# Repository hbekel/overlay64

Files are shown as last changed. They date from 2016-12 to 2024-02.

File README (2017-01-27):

overlay64 - video overlay module

The overlay64 module allows superimposing predefined texts onto an
existing composite signal or onto the luminance portion of an s-video
signal depending on the states of up to sixteen digital input
lines. An LM1881 video sync separator IC is used to detect the
vertical and horizontal sync pulses of the video signal. An Atmega1284
uses these signals to synchronize with the video signal and to
superimpose text on the video display by bit-banging the corresponding
characters over SPI.

The user writes a simple configuration file that determines which
texts are to be displayed for which input line states. The
configuration file is converted to a binary format using the supplied
commandline tool before flashing it to the Atmegas's eeprom memory via
the USB interface.

Possible uses include displaying the state of control lines for
additional hardware installed in a homecomputer such as the Commodore
64, for example to display the currently selected kernal based on the
state of the control lines for a multi-kernal adapter.

An early working prototype can be seen in this video where it displays
the runtime configuration of the MixSID Stereo SID board:

https://www.youtube.com/watch?v=0exp2yM0WHM

This repository includes the complete sourcecode of the client
software, the firmware and all design files in KiCAD format.

LICENSING

Hardware licenced under CERN OHL v.1.2, see ./hardware/LICENSE.txt
Software and firmware licenced under GNU GPLv3, see ./LICENSE

The software contains MIT licensed code from
https://github.com/arkku/ihex for reading Intel HEX files, Copyright
(c) 2013-2015 Kimmo Kulovesi, see ./intelhex/LICENSE

The firmware contains the V-USB Driver (https://www.obdev.at/vusb),
(C)2008 Objective Development GmbH.

Distributed in the ./bootloader directory is the USBasp bootloader,
(C)2013 Stephan Baerwolf (matrixstorm@gmx.de) and (C)2008 Objective
Development GmbH (https://www.obdev.at/vusb).

In compliance with the terms of the (identical) V-USB driver and
USBasp bootloader licenses (./firmware/usbdrv/License.txt and
./bootloader/License.txt), the entire project is published under

http://www.henning-bekel.de/overlay64

In addition, this distribution contains

- a circuit diagram in PDF format, see ./hardware/overlay64-schematics.pdf
- the full source code for the host software in ./firmware
- this README file
- references to https://www.obdev.at/vusb

The USB Product and Vendor IDs for the Overlay64 USB device have kindly
been provided by OpenMoko, Inc (http://openmoko.org).

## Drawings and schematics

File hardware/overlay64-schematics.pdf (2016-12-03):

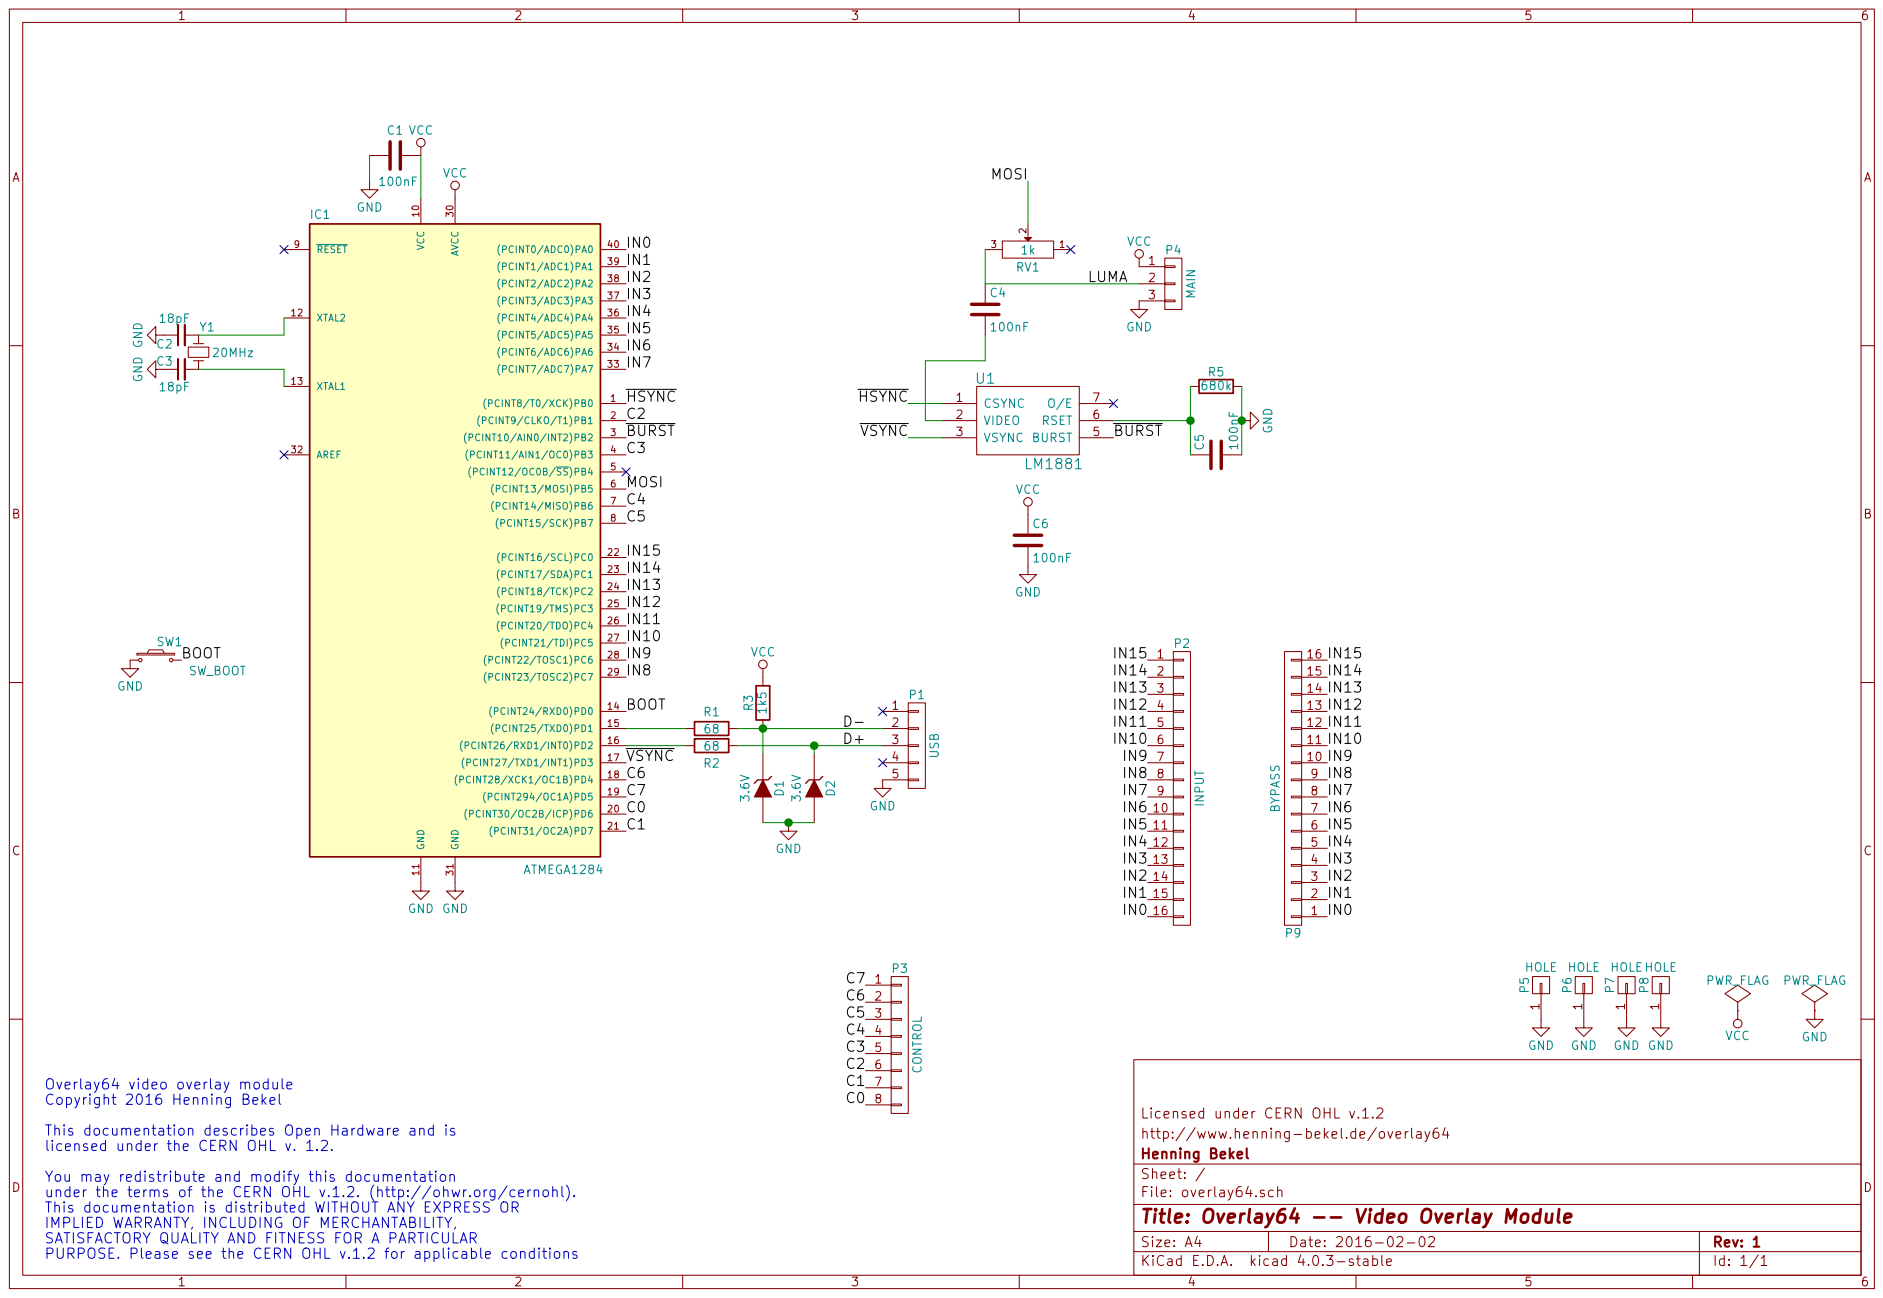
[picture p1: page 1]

1 P8 HOLE GND GND GND GND

Copyright 2016 Henning Bekel
This documentation describes Open Hardware and is
licensed under the CERN OHL v. 1.2.
You may redistribute and modify this documentation
under the terms of the CERN OHL v.1.2. (http://ohwr.org/cernohl).
This documentation is distributed WITHOUT ANY EXPRESS OR
IMPLIED WARRANTY, INCLUDING OF MERCHANTABILITY,
SATISFACTORY QUALITY AND FITNESS FOR A PARTICULAR
PURPOSE. Please see the CERN OHL v.1.2 for applicable conditions

Licensed under CERN OHL v.1.2
http://www.henning-bekel.de/overlay64
File: overlay64.sch Sheet: / Henning Bekel

Id: 1/1 Title: Overlay64 -- Video Overlay Module

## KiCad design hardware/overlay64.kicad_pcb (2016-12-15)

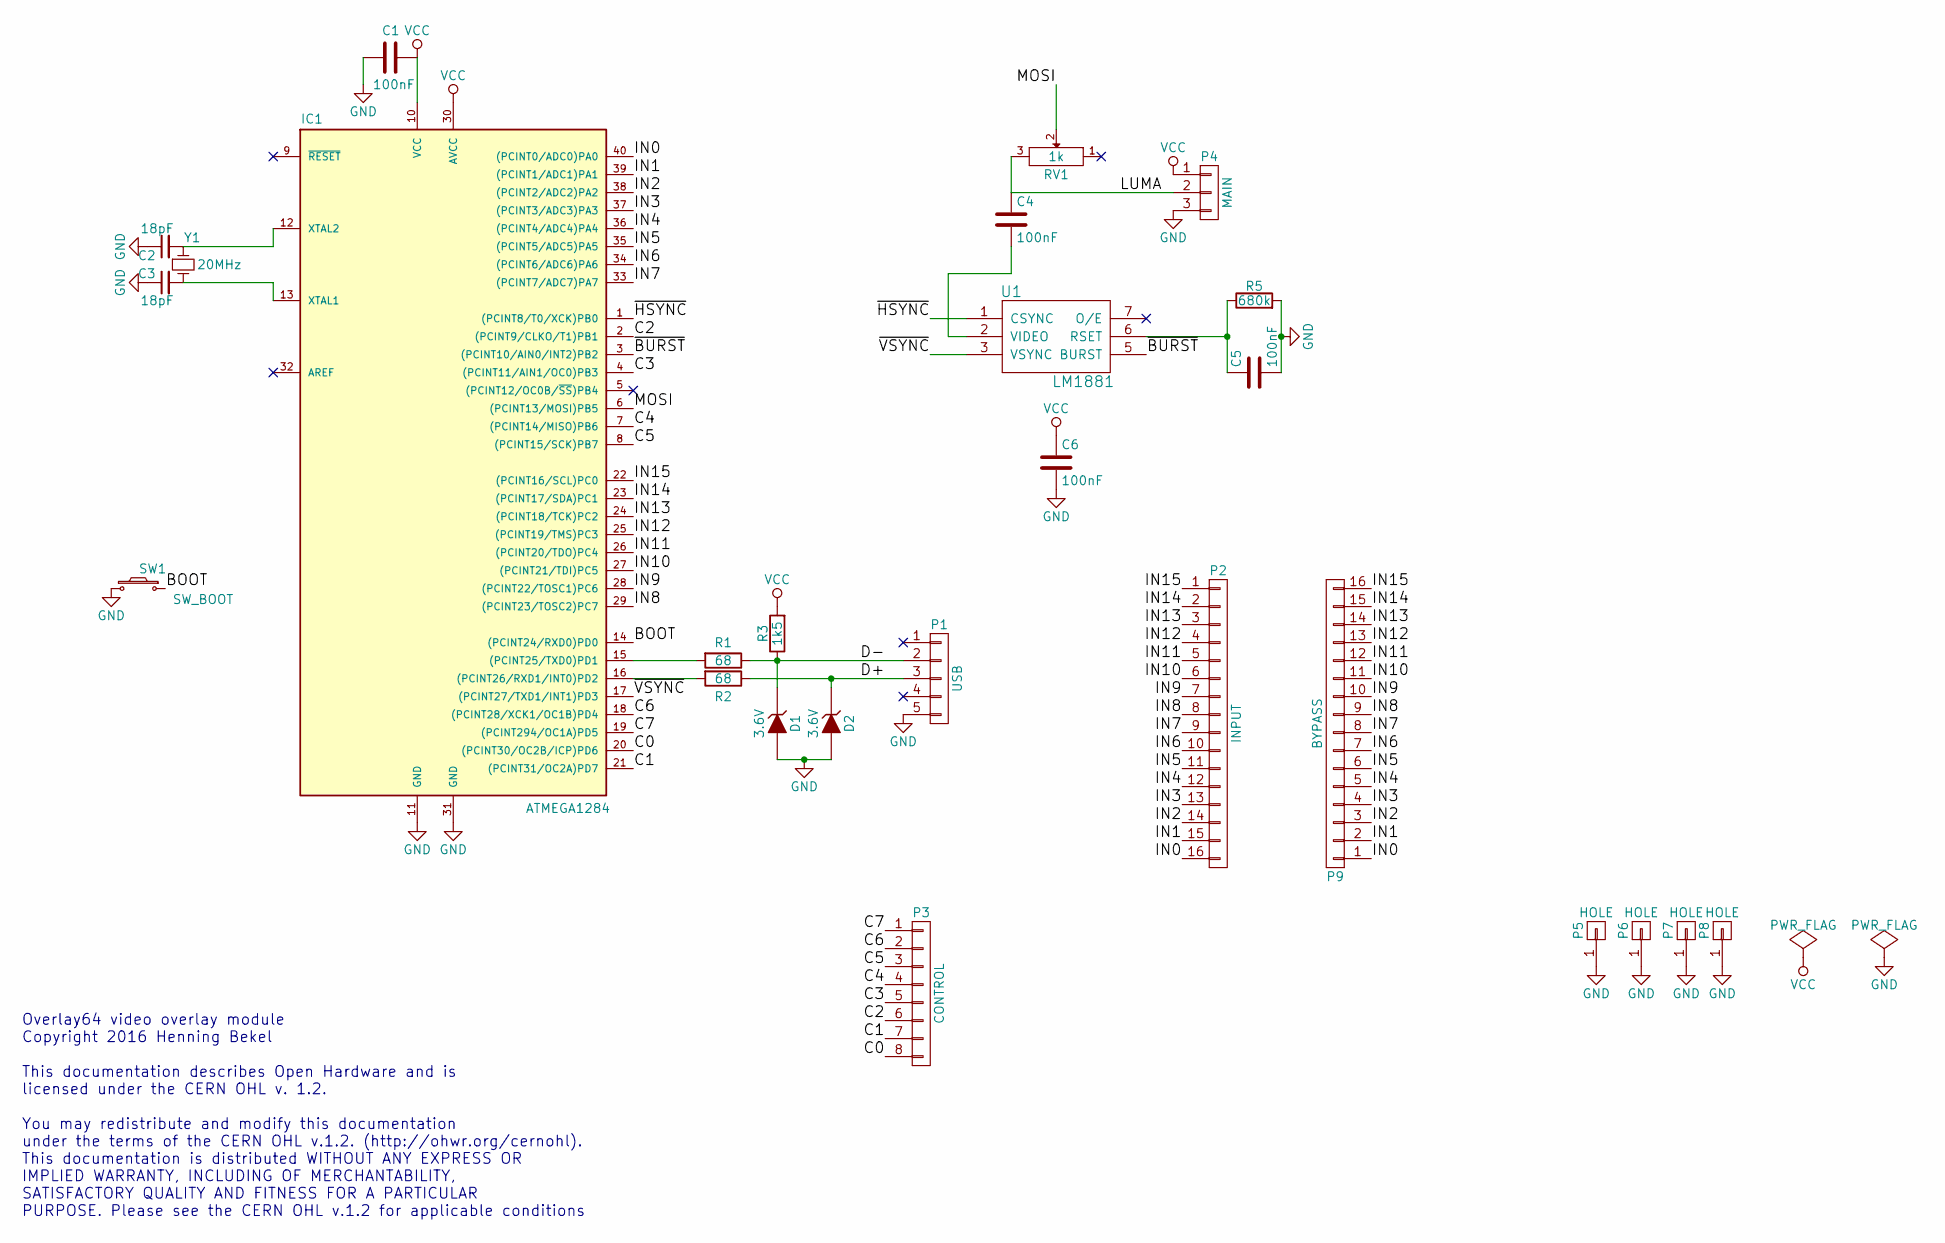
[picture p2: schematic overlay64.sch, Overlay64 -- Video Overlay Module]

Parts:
C1, C4, C5, C6: 100nF; C_Disc_D3_P2.5
C2, C3: 18pF; C_Disc_D3_P2.5
D1, D2: 3.6V; D3
IC1: ATMEGA1284; DIP-40_W15.24mm
P1: USB; USB-MINI-B-TH
P2: INPUT; Pin_Header_Angled_1x16
P3: CONTROL; Pin_Header_Angled_1x08
P4: MAIN; Pin_Header_Angled_1x03
P5, P6, P7, P8: HOLE; MountingHole_4mm
P9: BYPASS; Pin_Header_Angled_1x16
R1, R2: 68; R3
R3: 1k5; R3
R5: 680k; R3
RV1: 1k; Potentiometer_Bourns_3339P_Angular_ScrewUp
SW1: SW_BOOT; Button
U1: LM1881; DIP-8_W7.62mm
Y1: 20MHz; Crystal_HC49-U_Vertical

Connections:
/BOOT: IC1.14 ((PCINT24/RXD0)PD0), SW1.2
/C0: IC1.20 ((PCINT30/OC2B/ICP)PD6), P3.8
/C1: IC1.21 ((PCINT31/OC2A)PD7), P3.7
/C2: IC1.2 ((PCINT9/CLKO/T1)PB1), P3.6
/C3: IC1.4 ((PCINT11/AIN1/OC0)PB3), P3.5
/C4: IC1.7 ((PCINT14/MISO)PB6), P3.4
/C5: IC1.8 ((PCINT15/SCK)PB7), P3.3
/C6: IC1.18 ((PCINT28/XCK1/OC1B)PD4), P3.2
/C7: IC1.19 ((PCINT294/OC1A)PD5), P3.1
/D+: D2.1 (K), P1.3, R2.1
/D-: D1.1 (K), P1.2, R1.1, R3.1
/IN0: IC1.40 ((PCINT0/ADC0)PA0), P2.16, P9.1
/IN1: IC1.39 ((PCINT1/ADC1)PA1), P2.15, P9.2
/IN2: IC1.38 ((PCINT2/ADC2)PA2), P2.14, P9.3
/IN3: IC1.37 ((PCINT3/ADC3)PA3), P2.13, P9.4
/IN4: IC1.36 ((PCINT4/ADC4)PA4), P2.12, P9.5
/IN5: IC1.35 ((PCINT5/ADC5)PA5), P2.11, P9.6
/IN6: IC1.34 ((PCINT6/ADC6)PA6), P2.10, P9.7
/IN7: IC1.33 ((PCINT7/ADC7)PA7), P2.9, P9.8
/IN8: IC1.29 ((PCINT23/TOSC2)PC7), P2.8, P9.9
/IN9: IC1.28 ((PCINT22/TOSC1)PC6), P2.7, P9.10
/IN10: IC1.27 ((PCINT21/TDI)PC5), P2.6, P9.11
/IN11: IC1.26 ((PCINT20/TDO)PC4), P2.5, P9.12
/IN12: IC1.25 ((PCINT19/TMS)PC3), P2.4, P9.13
/IN13: IC1.24 ((PCINT18/TCK)PC2), P2.3, P9.14
/IN14: IC1.23 ((PCINT17/SDA)PC1), P2.2, P9.15
/IN15: IC1.22 ((PCINT16/SCL)PC0), P2.1, P9.16
/LUMA: C4.1, P4.2, RV1.3
/MOSI: IC1.6 ((PCINT13/MOSI)PB5), RV1.2
/~BURST: IC1.3 ((PCINT10/AIN0/INT2)PB2), U1.5 (BURST)
/~HSYNC: IC1.1 ((PCINT8/T0/XCK)PB0), U1.1 (CSYNC)
/~VSYNC: IC1.17 ((PCINT27/TXD1/INT1)PD3), U1.3 (VSYNC)
GND: C1.2, C2.1, C3.1, C5.2, C6.2, D1.2 (A), D2.2 (A), IC1.11 (GND), IC1.31 (GND), P1.5, P4.3, P5.1, P6.1, P7.1, P8.1, R5.2, SW1.1, U1.4 (GND)
unnamed: C2.2, IC1.12 (XTAL2), Y1.1
unnamed: C3.2, IC1.13 (XTAL1), Y1.2
unnamed: C4.2, U1.2 (VIDEO)
unnamed: C5.1, R5.1, U1.6 (RSET)
unnamed: IC1.15 ((PCINT25/TXD0)PD1), R1.2
unnamed: IC1.16 ((PCINT26/RXD1/INT0)PD2), R2.2
VCC: C1.1, C6.1, IC1.10 (VCC), IC1.30 (AVCC), P4.1, R3.2, U1.8 (VCC)

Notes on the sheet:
Overlay64 video overlay module Copyright 2016 Henning Bekel This documentation describes Open Hardware and is licensed under the CERN OHL v. 1.2. You may redistribute and modify this documentation under the terms of the CERN OHL v.1.2. (http://ohwr.org/cernohl). This documentation is distributed WI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

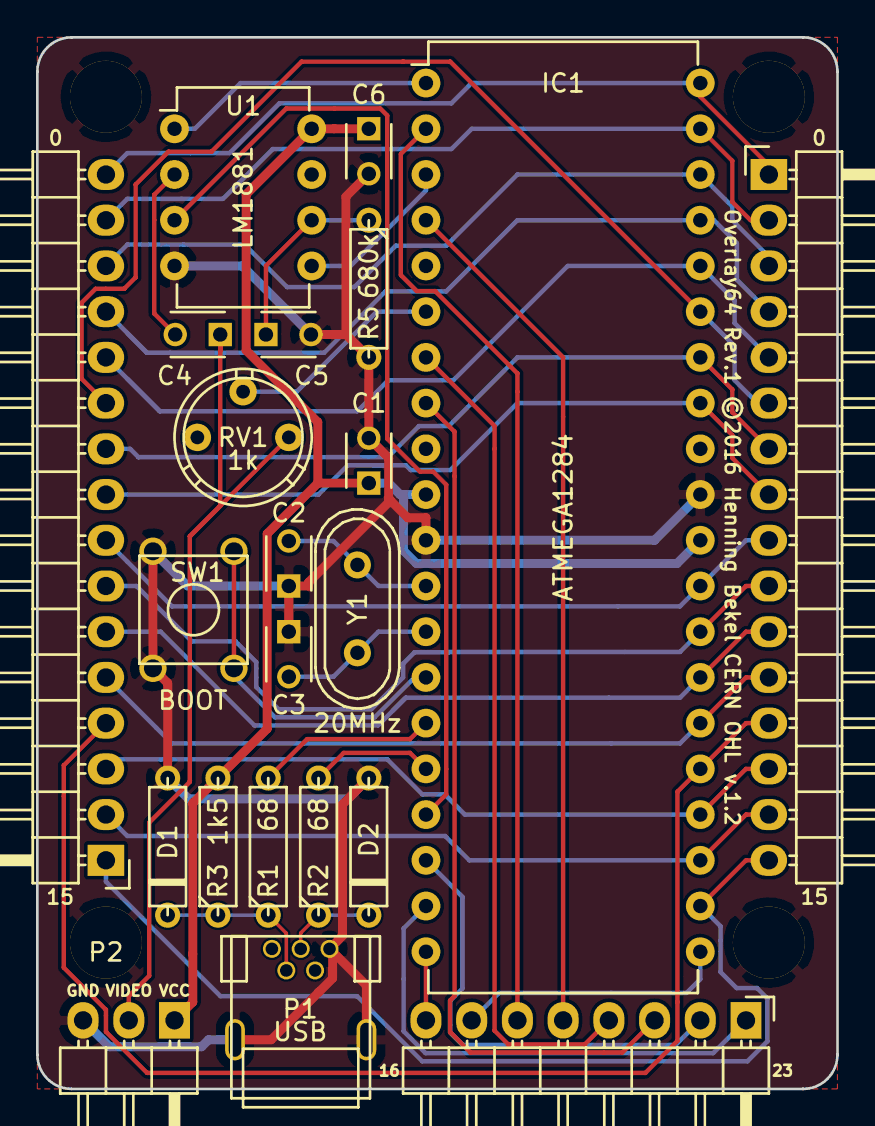
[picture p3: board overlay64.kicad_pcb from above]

Board: 2 copper layers, 44.5 x 58.4 mm, 26 parts (0 on the bottom side), 40 nets.

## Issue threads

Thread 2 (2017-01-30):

Device resets into Bootloader after config is sent

c0zmo, 2017-01-30:
I compiled software and firmware from todays sources (30 Jan 17). Now, with "overlay64 configure config.txt" the config is translated and sent to the device, but then it shows "Resetting device......" for 6-8 seconds. After that, the Overlay64 is in boot loader mode.
I'm using Prototype V2 Hardware, if that matters...

hbekel, 2017-01-30:
Please make sure you are actually using both the new firmware and the new software ($ which overlay64).

The device should not be in bootloader mode, since flashing the configuration does no longer involve the bootloader at all. The only reason I can think of is that you are still using the old client.

c0zmo, 2017-01-30:
Firmware and software are from the current branch. I just re-installed the firmware, and there the reset works:

```
markus@LE752:~/overlay64-master-20170130/firmware$ overlay64 update main.hex
Trying to parse Intel HEX format...OK
Parsed 17152 bytes starting at 0x00
Entering bootloader..
USBaspLoader (C)2008 by OBJECTIVE DEVELOPMENT Software GmbH
Updating application: 17152 of 17152 bytes transferred...OK
Resetting device...
overlay64 firmware 1.0 Jan 30 2017 18:50:01
```

But when flashing the config, the device stays in Bootloader-mode:

...
markus@LE752:~/overlay-config$ overlay64 configure o64-c0z.conf
Reading o64-c0z.conf...
SRAM:	 3249 of 16384 bytes used (13135 bytes free)
EEPROM:	  866 of  4096 bytes used ( 3230 bytes free)
Flashing configuration: 866 bytes...ok
Resetting device..........markus@LE752:~/overlay-config$ overlay64 identify
USBaspLoader (C)2008 by OBJECTIVE DEVELOPMENT Software GmbH
...

Using the reset-command works though.

c0zmo, 2017-09-14:
Just an update, even with the latest firmware this issue is still there. Maybe you can take a look at it this weekend. ;-)

hbekel, 2017-09-14:
I could not reproduce this issue and I haven't had anyone else reporting this, so I assume the issue is somewhere on your system. We can look into it tomorrow :)

c0zmo, 2017-09-20:
As it turned out, the problem seems to have been my self-compiled firmware. After we flashed the stock bootloader and firmware image with your computer on DoReCo, the problem disappeared.

Sorry for any inconvenience.
c0z

Closed 2017-11-05.

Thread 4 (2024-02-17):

New feature idea: draw bad lines, borders etc.

r1me, 2024-02-17:
How about drawing something else than text and would be helpful for coders and artists, like:
- bad lines (no doubt coders would like to have this feature) ignore FLD or whatever can delay bad lines, simply draw a dotted line where they normally occur
- borders of foreground (i.e. with same foreground and background color it's hard to tell if something is off center)
- margins of visible area (customizable x1, y1, x2, y2) once set that can be later used for calibrating projectors/CRTs for C64 video output, like https://csdb.dk/release/?id=201894 does

More or less that's what came to my mind.

hbekel, 2024-02-17:
Those ideas are nice, but unfortunately they are not really feasible for a simple project like this.

1. Drawing bad lines -- this is completely out of scope for this hardware. The overlay64 only sees a PAL signal, and knows nothing about the C64 or the VIC. Even if some other device, say an FPGA VIC implementation, would provide an additional output line and assert it for the duration of a bad line, the overlay would not be able to pick it up and mark it in realtime. It is either completely busy bitbanging on the luminance signal for displaying the current (previously calculated) text buffer, OR it is sampling input lines and preparing the text buffer for display, but it can't do both simultaneously.

2. Drawing horizontal or vertical lines could be achieved by using a custom font and preparing a static text screen. However, since the overlay produces a higher horizontal resolution than the VIC (about 53*8=424 pixels), you probably wont be able to line it up exactly with something like the edge of the VIC border.

hbekel, 2024-02-17:
By the way, if you had an fpga VIC or some other magical device providing such a hypothetical output line (that would go high during badlines), you wouldn't even need the overlay to mark that line, you'd just have to switch a transistor to pull the luminance signal high. Limit the current with a resistor to make it semi-transparent, and you could still see what happens on the actual VIC line.

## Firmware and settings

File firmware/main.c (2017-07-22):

//-----------------------------------------------------------------------------
// Overlay64 -- Video Overlay Driver -- Atmega1284 @ 20MHz
//-----------------------------------------------------------------------------

/*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
  You should have received a copy of the GNU General Public License
  along with this program.  If not, see <http://www.gnu.org/licenses/>.
*/

#include <avr/io.h>
#include <avr/wdt.h>
#include <avr/interrupt.h>
#include <avr/eeprom.h>
#include <util/delay.h>
#include <stdlib.h>
#include <string.h>
#include <ctype.h>

#include "main.h"
#include "font.h"
#include "eeprom.h"
#include "config.h"
#include "usbdrv/usbdrv.h"
#include "../protocol.h"

#define MOSI (1<<PB5)  // SPI output pin (where the actual bitmap data is send)
#define SS   (1<<PB4)  // SPI slave select (must be pulled up in master mode)

#define ENABLE_SPI  DDRB |= MOSI  // Enable the SPI output pin
#define DISABLE_SPI DDRB &= ~MOSI // Disable (tristate) the SPI output pin

volatile uint16_t scanline; // current scanline of the whole video frame

volatile Config* config;    // Configuration is read from eeprom

static volatile bool reset = false; // Requests a reset from USB
static volatile char version[64];   // Version string

static volatile uint8_t usbCommand;
static volatile uint16_t usbDataReceived;
static volatile uint16_t usbDataLength;
static volatile uint8_t *usbData;
static volatile uint16_t usbDataPos;

//-----------------------------------------------------------------------------

static void setup() {

  wdt_disable();
  CheckBootloader();
  
  // Initialize Version string and font data
  SetupVersionString();  
  SetupFont();
  
  // Create config and assign ports
  config = Config_new_with_ports(&PINA, &PINB, &PINC, &PIND);

  // Read config from eeprom
  Config_read(config, &eeprom) || Config_install_fallback(config);

  // Setup INT1, INT2 and PCINT8 pins
  DDRB &= ~(1<<PB2);
  PORTB |= (1<<PB2);

  DDRD &= ~(1<<PD3);
  PORTD |= (1<<PD3); 

  DDRB &= ~(1<<PB0);
  PORTB |= (1<<PB0);
  
  // Setup Interrupts
  EICRA = (1<<ISC11) | (1<<ISC21); // Sense INT1 and INT2 on falling edge
  EIMSK = (1<<INT1);               // Enable interrupt for INT1 (vsync)

  // Setupt Pin Change Interrupt PCINT8 (hsync)
  PCICR = (1<<PCIE1);
  PCMSK1 = (1<<PCINT8);

  // Turn off ADC  
  ADCSRA &= ~(1<<ADEN); 

  // Turn off JTAG
  MCUCR |= (1<<JTD);
  
  // Setup SPI 
  DDRB = SS | MOSI;                // /SS and MOSI as outputs
  SPCR =
    (1<<SPE) | (1<<MSTR) |         // Enable SPI as Master
    (1<<CPHA) | (1<<CPOL);         // Setup with falling edge of SCK
  SPSR = (1<<SPI2X);               // Double speed

  // Setup input and control lines
  Config_setup(config);
  
  // Setup USB
  usbInit();

  usbDeviceDisconnect();
  
  _delay_ms(500);

  usbDeviceConnect();
  
  // Enable Interrupts
  sei();   
}

//-----------------------------------------------------------------------------

void DisableDisplay(void) {
  EIMSK &= ~(1<<INT2);
  PCICR = 0; 
}

//-----------------------------------------------------------------------------

ISR(INT1_vect, ISR_NOBLOCK) { // VSYNC (each frame)...
  
  // Decrease timeout counters for all screens
  Config_tick(config);
   
  // Reset scanline counter
  scanline = 0;
}

//-----------------------------------------------------------------------------

ISR(PCINT1_vect, ISR_NOBLOCK) { // HSYNC (each line)...
  
  // Return immediately unless pin has changed to low
  if(PINB & (1<<PB0)) return;

  // When we enter here, there's a jitter of 1-3 cycles due to code
  // executed in the mainloop. Therefore we'll use the BACK PORCH
  // signal from the LM1881, which is triggered about 8us after HSYNC,
  // to trigger another interrupt while only executing NOPS. This way
  // the next interrupt gets triggered after a fixed number of cycles,
  // and the display is reasonable stable. There is still a slight
  // overall instability in the display since the video and avr clocks
  // are not perfectly synchronized to start with.

  // Disable PCINT1 (HSYNC), enable INT2 (BACK PORCH)
  PCICR = 0;
  EIMSK |= (1<<INT2);
  
  // Enter INT2_vect somewhere along these nops...
  ONEHUNDRED_AND_TEN_NOPS();

  // Now we're back from INT2_vect, at the end of the line

  // Disable the SPI pin to avoid disturbing the next hsync.
  DISABLE_SPI;
  
  // Disable INT2 (BACK PORCH), enable PCINT1 (HSYNC) again
  EIMSK &= ~(1<<INT2);
  PCICR = (1<<PCIE1);
}

//-----------------------------------------------------------------------------

ISR(INT2_vect, ISR_NOBLOCK) { // BACK PORCH (8us after HSYNC)

  uint8_t* row;   // Character data for the current row
  uint8_t line;   // Logical line of the visible screen
  uint8_t column; // Current character column in the current row 
  uint8_t byte;   // Current byte offset into the character bitmap
  
  scanline++;

  if(config->enabled && (scanline >= SCREEN_TOP && scanline < SCREEN_BOTTOM)) {

    // The display is enabled and we're on a vertical line inside of
    // the logical screen area, but still outside of the visible
    // horizonzal area. So there is time to precalculate some values
    // for the current line...
    
    line = scanline - SCREEN_TOP;
    row = config->rows[line / CHAR_HEIGHT];
    byte = line % CHAR_HEIGHT;

    // ...and to decide whether we're on an empty row...
    if(row == NULL) goto skip;

    // ...not an empty row, so we'll enable the SPI Output pin...
    ENABLE_SPI;
    
    // ...and wait until the visible area is reached
    FORTYTWO_NOPS();

    // Bitbang font data for each column via SPI
    for(column=0; column<SCREEN_COLUMNS; column++) {
      SPDR = font[row[column]*CHAR_HEIGHT+byte];
      TWO_NOPS();
    }
  }  
  else {
    // The display is not enabled or we're outside of the logical screen
    // or there is nothing to display on this row...
    
  skip:
    // We'll tristate the SPI pin again
    DISABLE_SPI;
  }
}

//-----------------------------------------------------------------------------

void Reset(void) {
  cli();
  wdt_enable(WDTO_250MS);
  for(;;);
}

//-----------------------------------------------------------------------------

void CheckBootloader(void) {
  DDRD &= ~(1<<PD0);
  PORTD |= (1<<PD0);

  if((PIND & (1<<PD0)) == 0) {
    EnterBootloader();
    Reset();
  }
}

//-----------------------------------------------------------------------------

void EnterBootloader(void) {
  eeprom_update_word((uint16_t *)0x0ffe, (uint16_t) 0xb0b0);
  reset = true;
}

//-----------------------------------------------------------------------------

void SetupVersionString(void) {

  char *v = "overlay64 firmware " xstr(VERSION) " " __DATE__ " " __TIME__;
  int len = strlen(v);

  for(uint8_t i=0; i<64; i++) {
    version[i] = '\0';
  }
  uint8_t o=0;
  
  for(uint8_t i=0; i<strlen(v); i++) {
    if(i>1 && v[i-1] == ' ' && v[i] == ' ') continue;
    version[o++] = v[i];
  }
}

//-----------------------------------------------------------------------------

USB_PUBLIC usbMsgLen_t usbFunctionSetup(uint8_t data[8]) {

  usbRequest_t *usbRequest = (void*) data;

  switch(usbRequest->bRequest) {

  case OVERLAY64_FLASH:
    DisableDisplay();
    
    usbCommand = usbRequest->bRequest;
    usbDataLength = usbRequest->wLength.word;
    usbDataReceived = 0;
    
    if(usbData == NULL) {
      usbData = (uint8_t*) calloc(1, sizeof(uint8_t) * usbDataLength);
    }
    
    return USB_NO_MSG;
    break;
    
  case OVERLAY64_BOOT:
    DisableDisplay();
    EnterBootloader();   
    break;

  case OVERLAY64_RESET:
    eeprom_update_word((uint16_t *)0x0ffe, (uint16_t) 0xffff);
    reset = true;
    break;
    
  case OVERLAY64_IDENTIFY:
    usbMsgPtr = (uchar *) version;
    return strlen((const char*)version)+1;
    break;
    
  default:
    break;
  }
  return 0;
}

//-----------------------------------------------------------------------------

USB_PUBLIC uchar usbFunctionWrite(uchar *data, uchar len) {

  for(int i=0; usbDataReceived < usbDataLength && i < len; i++, usbDataReceived++) {
    usbData[usbDataReceived] = (uint8_t) data[i];
  }

  if(usbDataReceived < usbDataLength) {
    return 0;
  }
  else {
    if(usbCommand == OVERLAY64_FLASH) {
      FlashConfigurationFromUSBData();
    }
  }
  
  free((void*)usbData);
  usbData = NULL;
  return 1;
}

//-----------------------------------------------------------------------------

void FlashConfigurationFromUSBData(void) {  
  fwrite((void*)usbData, sizeof(uint8_t), usbDataLength, &eeprom);
  eeprom_update_word((uint16_t *)0x0ffe, (uint16_t) 0xffff);
  reset = true;
}

//-----------------------------------------------------------------------------

void SetupFont(void) {
  for(uint16_t i=0; i<96*8; i++) {
    font[i] = pgm_read_byte(&(_font[i]));
  }
}

//-----------------------------------------------------------------------------

int main(void) {

  setup();

  while(1) {

    // Poll for USB messages
    usbPoll();

    // If reset is requested, allow USB communication to finish, then reset
    if(reset) {
      _delay_ms(250);
      Reset();
    }
    
    // Sample input/control lines and update screen according to user config
    Config_apply(config);
  }
  
  return 0;    
}

//-----------------------------------------------------------------------------

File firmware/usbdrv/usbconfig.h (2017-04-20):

/* Name: usbconfig.h
 * Project: V-USB, virtual USB port for Atmel's(r) AVR(r) microcontrollers
 * Author: Christian Starkjohann
 * Creation Date: 2005-04-01
 * Tabsize: 4
 * Copyright: (c) 2005 by OBJECTIVE DEVELOPMENT Software GmbH
 * License: GNU GPL v2 (see License.txt), GNU GPL v3 or proprietary (CommercialLicense.txt)
 */

#ifndef __usbconfig_h_included__
#define __usbconfig_h_included__

/*
General Description:
This file is an example configuration (with inline documentation) for the USB
driver. It configures V-USB for USB D+ connected to Port D bit 2 (which is
also hardware interrupt 0 on many devices) and USB D- to Port D bit 4. You may
wire the lines to any other port, as long as D+ is also wired to INT0 (or any
other hardware interrupt, as long as it is the highest level interrupt, see
section at the end of this file).
+ To create your own usbconfig.h file, copy this file to your project's
+ firmware source directory) and rename it to "usbconfig.h".
+ Then edit it accordingly.
*/

/* ---------------------------- Hardware Config ---------------------------- */

#define USB_CFG_IOPORTNAME      D
/* This is the port where the USB bus is connected. When you configure it to
 * "B", the registers PORTB, PINB and DDRB will be used.
 */
#define USB_CFG_DMINUS_BIT      1
/* This is the bit number in USB_CFG_IOPORT where the USB D- line is connected.
 * This may be any bit in the port.
 */
#define USB_CFG_DPLUS_BIT       2
/* This is the bit number in USB_CFG_IOPORT where the USB D+ line is connected.
 * This may be any bit in the port. Please note that D+ must also be connected
 * to interrupt pin INT0! [You can also use other interrupts, see section
 * "Optional MCU Description" below, or you can connect D- to the interrupt, as
 * it is required if you use the USB_COUNT_SOF feature. If you use D- for the
 * interrupt, the USB interrupt will also be triggered at Start-Of-Frame
 * markers every millisecond.]
 */
#define USB_CFG_CLOCK_KHZ       (F_CPU/1000)
/* Clock rate of the AVR in kHz. Legal values are 12000, 12800, 15000, 16000,
 * 16500, 18000 and 20000. The 12.8 MHz and 16.5 MHz versions of the code
 * require no crystal, they tolerate +/- 1% deviation from the nominal
 * frequency. All other rates require a precision of 2000 ppm and thus a
 * crystal!
 * Since F_CPU should be defined to your actual clock rate anyway, you should
 * not need to modify this setting.
 */
#define USB_CFG_CHECK_CRC       0
/* Define this to 1 if you want that the driver checks integrity of incoming
 * data packets (CRC checks). CRC checks cost quite a bit of code size and are
 * currently only available for 18 MHz crystal clock. You must choose
 * USB_CFG_CLOCK_KHZ = 18000 if you enable this option.
 */

/* ----------------------- Optional Hardware Config ------------------------ */

/* #define USB_CFG_PULLUP_IOPORTNAME   D */
/* If you connect the 1.5k pullup resistor from D- to a port pin instead of
 * V+, you can connect and disconnect the device from firmware by calling
 * the macros usbDeviceConnect() and usbDeviceDisconnect() (see usbdrv.h).
 * This constant defines the port on which the pullup resistor is connected.
 */
/* #define USB_CFG_PULLUP_BIT          4 */
/* This constant defines the bit number in USB_CFG_PULLUP_IOPORT (defined
 * above) where the 1.5k pullup resistor is connected. See description
 * above for details.
 */

/* --------------------------- Functional Range ---------------------------- */
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

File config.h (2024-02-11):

/*
overlay64 -- video overlay module
Copyright (C) 2016 Henning Bekel

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
You should have received a copy of the GNU General Public License
along with this program.  If not, see <http://www.gnu.org/licenses/>.
*/

#ifndef CONFIG_H
#define CONFIG_H

#include <stdint.h>
#include <stdbool.h>
#include <stdio.h>

#define CHAR_WIDTH    8
#define CHAR_HEIGHT   8

#define SCREEN_COLUMNS 52
#define SCREEN_ROWS    30

#define SCREEN_TOP    46
#define SCREEN_BOTTOM SCREEN_TOP + CHAR_HEIGHT * SCREEN_ROWS

#define MODE_MANUAL 1
#define MODE_NOTIFY 2
#define MODE_ALWAYS 3

#define NUM_PINS 24

#define ACTION_NONE  0x00
#define ACTION_WRITE 0x01
#define ACTION_CLEAR 0x02

extern uint8_t CONFIG_MAGIC[2];

typedef struct {
  uint8_t volatile *port; // pointer into Config->ports
  uint8_t pos;
  uint8_t edge[2];
} Pin;

typedef struct {
  Pin* pin;

  uint8_t mode;
  bool asserted;

  uint8_t *screens; // index into config->screens
  uint8_t num_screens;

} Control;

typedef struct {
  void *screen;
  uint8_t action;
  uint8_t row;
  uint8_t col;
  uint16_t len;
  char* string; // pointer into config->strings
} Command;

typedef struct {
  void *screen;
  Command **commands;
  uint8_t num_commands;
} CommandList;

typedef struct {
  void *screen;
  Pin **pins; // pointers into Config->pins
  uint8_t num_pins;
  uint8_t value;

  CommandList *command_list; // immediate commands

  CommandList **command_lists; // one command list for each state
  uint8_t num_command_lists;
} Sample;

typedef struct {
  uint8_t mode;
  bool enabled;
  uint8_t timeout;

  Sample **samples;
  uint8_t num_samples;

  Control **controls;
  uint8_t num_controls;

  CommandList* commands;

  uint8_t **rows;

} Screen;

typedef struct {
  uint8_t volatile *ports[4]; // the actual ports to use
  Pin *pins[NUM_PINS];        // the available pins

  bool enabled;
  uint8_t timeout;

  char **strings;
  uint8_t num_strings;

  Control **controls;
  uint8_t num_controls;

  Screen **screens;
  uint8_t num_screens;

  uint8_t **rows;

} Config;

volatile Config *Config_new(void);
volatile Config* Config_new_with_ports(uint8_t volatile *a,
                                       uint8_t volatile *b,
                                       uint8_t volatile *c,
                                       uint8_t volatile *d);

Control* Config_add_control(volatile Config *self, Control* control);
Screen* Config_add_screen(volatile Config *self, Screen* screen);
bool Config_has_string(volatile Config *self, char* string, uint8_t *index);
char *Config_add_string(volatile Config *self, char* string);
bool Config_read(volatile Config *self, FILE *in);
void Config_each_command(volatile Config* self,
                         void (*callback)(Screen* screen, Command* command));
void Config_allocate_row_for_command(Screen* screen, Command *command);
void Config_allocate_rows(volatile Config *self);
void Config_assign_controls_to_screens(volatile Config* self);
bool Config_install_fallback(volatile Config* self);
void Config_free(volatile Config* self);

Control* Control_new(void);
void Control_add_screen(Control* self, uint8_t index);
void Control_read(Control* self, FILE* in);
void Control_free(Control* self);

Screen* Screen_new(void);
Screen* Screen_add_control(Screen *self, Control* control);
Sample* Screen_add_sample(Screen *self, Sample* sample);
void Screen_read(Screen* self, FILE* in);
void Screen_free(Screen* self);

Sample* Sample_new(Screen* screen);
Pin* Sample_add_pin(Sample* self, Pin* pin);
void Sample_read(Sample* self, FILE* in);
CommandList* Sample_add_commands(Sample* self, CommandList* commands);
void Sample_free(Sample* self);

Command* Command_new(Screen *screen);
void Command_set_string(Command* self, char *string);
bool Command_equals(Command* self, Command* command);
void Command_read(Command* self, FILE* in);
void Command_free(Command* self);

CommandList* CommandList_new(Screen* screen);
Command* CommandList_add_command(CommandList *self, Command* command);
void CommandList_read(CommandList *self, FILE *in);
void CommandList_free(CommandList* self);

Pin *Pin_new(volatile Config* config, uint8_t port, uint8_t pos);
void Pin_free(Pin *self);

#endif // CONFIG_H

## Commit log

2016-01-22 Intial commit, rough draft
    [overlay64.kicad_pcb, overlay64.sch]
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2016-01-26 Hardware: Schematics switched to 1284P including USB, still drafting...
    [overlay64.sch]
2016-01-27 Hardware: Switched to atmega32p, updated to current state on breadboard
    [overlay64.sch]
2016-01-27 Hardware: Added vic sockets, layed out components (rough draft)
    [overlay64.kicad_pcb, overlay64.sch]
2016-01-28 Hardware: Removed VIC-Sockets and pcb layout
    Designing this as a VIC-Adpater-board is too complicated, and maybe
    not possible (depending on what the modulator still does to the signal
    to make it a proper C/Y signal).
    It's probably simpler to get LUMA from the connector internally.
    [overlay64.kicad_pcb, overlay64.sch]
2016-01-28 Hardware: Updated schematics, Added /OE, resistor before transistor base
    [overlay64.sch]
2016-01-29 Firmware: Fixed conditional compile in Makefile
    [main.c]
2016-02-02 Firmware: Fixed sparse memory model, expanded screen to 53x30 chars max
    Always allocate a complete row of screen memory for each row used. This
    further speeds up access to the character data, resulting in even smaller
    horizontal gaps between characters.
    [config.c, config.h, main.c]
2016-02-02 Software: Fixed invalid free in Command_parse, fixed footprint calculation
2016-02-02 Hardware: Removed wrong "no connection" symbol on IN7
    [overlay64.sch]
2016-02-02 Hardware: Added dual 14 pin header for bypassing the inputs
    [overlay64.sch]
2016-02-02 Hardware: Specified correct transistor type (BC547B)
    [overlay64.sch]
2016-02-03 Hardware: Added jumper for backdrop (decreased luminance as background)
    [overlay64.sch]
2016-02-06 Firmware: Removed useless malloc for empty rows, use NULL pointers instead
    Since empty rows are skipped from display now, the memory allocated for the
    empty row is no longer used, so it can be saved.
    [config.c, config.h, main.c]
2016-02-06 Hardware: First draft of pcb layout (rough)
    [overlay64.dsn, overlay64.kicad_pcb, overlay64.sch]
2016-02-06 Revert "Firmware: Simplified rendering code"
    This reverts commit e1bf8339e2f7e9adda6c1a24c2130ea8e0cfa4bb.
    [main.c]
2016-02-08 Firmware: Added global output enable pin, improved control logic
    The former OE (output enable) pin has been renamed to OR (output request)
    and another pin has been introduced as OE (output enable).
    The output enable pin now directly controls whether or not the display is
    active. When low, the display is enabled. When going high again, the
    display is immediately disabled, regardless of any running timeouts from a
    former output request.
    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
    [overlay64.sch]
2016-02-08 Hardware: Updated netlist to include OE/OR pins
    [overlay64.kicad_pcb]
2016-02-08 Hardware: Adjusted input pin connections to new logical layout
    [overlay64.dsn, overlay64.kicad_pcb, overlay64.sch]
2016-05-09 Hardware: Rearranged components, rerouting...
    [overlay64.dsn, overlay64.kicad_pcb, overlay64.sch]
2016-05-24 Hardware: Improved routing
    [overlay64.kicad_pcb]
2016-05-24 Hardware: Fixed orientation/wiring for brightness pot
    [overlay64.kicad_pcb, overlay64.sch]
2016-05-24 Production: Added gerber files for Revision 1
    [overlay64.gbl, overlay64.gbs, overlay64.gtl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]
2016-07-21 Firmware/Software: Fixed memory footprint calculation, minor changes
    [config.c]
2016-07-28 Hardware: Changed schematics for 1284p, removed pcb layout
    [overlay64.kicad_pcb, overlay64.sch]
2016-07-28 Hardware: Corrected OE/OR pins, Software: Disable inputs for now
    [overlay64.sch]
2016-08-02 Firmware: Now applying config in main thread, stabilized hsync interrupts
    [config.c, config.h, main.c]
2016-08-02 Hardware: Updated schematics, added BURST signal connection
    [overlay64.sch]
2016-08-12 Hardware: Added custom components, started layout
    [overlay64.kicad_pcb, overlay64.sch]
2016-08-12 Hardware: First draft of new pcb layout, autorouted
    [overlay64.dsn, overlay64.kicad_pcb]
2016-08-14 Project: Fixed some file attributes, set alpha project version
    [overlay64.dsn, overlay64.sch]
2016-08-18 Hardware: Added jumpers for manually entering the bootloader
    [overlay64.dsn, overlay64.kicad_pcb, overlay64.sch]
2016-08-19 Hardware: Prototype 2, rearranged, rerouted, added gerber files
    [overlay64.dsn, overlay64.kicad_pcb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]
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2016-09-01 Firmware: Fixed jitter from USB INT0, ensure enumeration
    [main.c]
2016-09-06 Hardware: Removed explicit OE/OR lines, relabeled control lines
    [overlay64.kicad_pcb, overlay64.sch]
2016-09-07 Firmware: Fixed some bugs, sample pins only once per pass
    [config.c]
2016-09-08 Firmware: Fixed problems with controls/samples/notifications
    When a manual control enables a screen, cancel any pending
    notification for that screen.
    Initially sample the input/control lines, otherwise the first
    sampling is already interpreted as a change, triggering automatic
    screens.
    [config.c]
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2016-09-22 Hardware: Improved USB signal routing
    [overlay64.kicad_pcb]
2016-10-02 Software/Firmware: Removed distinction between input and control lines
    Now all input pins can be used either as an input line for sampling
    or as a control line. Pins are thus indexed from 0 to 23. The first
    16 lines are the ones passed through on the left and right side, the
    last 8 lines are the ones right of the USB adapter, where pin 16 is
    left and pin 23 is right.
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2016-11-27 Hardware: Removed backdrop option, single boot button, rerouting...
    [overlay64.dsn, overlay64.kicad_pcb, overlay64.sch]
2016-12-01 Hardware: Added 3d models for button and diodes
    [overlay64.kicad_pcb]
2016-12-01 Software: Implemented convert, configure, update and boot commands
    Also added options --version, --help, --device
2016-12-01 Firmware: Added fallback configuration in case of empty eeprom
    The fallback configuration simply displays some information
    when no valid configuation is found in eeprom memory. This will
    most likely be the case when the device is powered on for the
    first time.
2016-12-02 Software: Added reset command, improved boot command
    [main.c]
2016-12-03 Project: Hardware documentation licensed under CERN OHL 1.2
    [overlay64.kicad_pcb, overlay64.sch]
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2016-12-06 Software: Improved error messages for missing USB devices
2016-12-06 Hardware: Added rendering of component placement
    [overlay64.kicad_pcb]
2016-12-06 Software: Improved error messages, detect and report doubleclick on windows
    Complain if the user doubleclicks the .exe on windows and suggest running
    from a command prompt instead.
    Improved error messages for missing USB devices, added role to device info
    Fixed compiler warning concerning _fileno for native cygwin builds
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2016-12-08 Hardware: Updated gerber files for revision 1
    [overlay64.kicad_pcb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]
2016-12-09 Firmware: Added support for lowercase characters
    Expanded font to include all printable 7-bit ASCII characters
    (ASCII codes 32-127).
    Also some preparations for making the font customizable by the user.
    The default font.rom file in ./firmware now includes characters in
    ASCII order, which means it is no longer directly compatible with a
    c64 font file.
    Also, the font has been moved to a fixed address in PROGMEM (0x5000),
    which will allow selectively updating it from an appropriate .hex file
    using the update command in the future.
2016-12-10 Software/Firmware: More changes towards user customizable fonts
    The font data is now properly stored at a fixed progmem address
    and copied to sram at startup.
    Fixed size calculations when reading segmented ihex files, added
    code to allow writing in hex format files as well.
    Only ihex format is now allowed as input for the update command.
    [main.c]
2016-12-11 Software: Added command to convert c64 charsets to overlayt64 fonts
    $ overlay64 font-convert <infile> <outfile>
    $ overlay64 font-update <infile>
    The "font-convert" command converts a C64 charset image to an
    overlay64 font file.
    The "font" command has been renamed to "font-update" (transfer
    an overlay64 font file to the device).
2016-12-15 Hardware: Improved silkscreen, added labels
    [overlay64.kicad_pcb]
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2017-01-06 Firmware: Prevent writing past the end of a row
    [config.c]
2017-01-06 Software: Fixed bugs in parsing/reading clear commands
    [config.c]
2017-01-10 Version 1.0
    [overlay64.drl, overlay64.gbl, overlay64.gbs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]
2017-01-27 Software/Firmware: Improved display logic, improved flashing, bugfixes
    Improved screen logic. Independent of the screen or control mode,
    a screen is only enabled if at least one write command is found
    to be effective. This can either be an unconditional write command
    or a write command depending on a certain input line state.
    In addition, a sample does not need to cover all possible input
    line states anymore.
    The new screen mode "always" has been added to allow a screen to
    be always enabled regardless of control lines being asserted or
    input lines being changed, as far as at least one write command
    is effective.
    Combining both features allows for text to be displayed
    permanently when one o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
    [config.c, config.h, main.c]
2017-01-31 Firmware: Assure bootloader flag is cleared before reset
    [main.c]
2017-04-11 Firmware: Improved chances of proper device enumeration for some Windows versions.
    It appears that on some Windows versions and/or installations device
    enumeration may fail due to Windows giving up on enumeration too early.
    A workaround for the current 1.1 version of the firmware is to disconnect
    the cable from the PC when the device is powered on and to connect
    it to the PC after a few seconds.
    Thus the previously introduced delay has been removed again. Note
    that enumeration on Linux is/was not negatively affected by either
    variant.
    Thanks Richard van der Wolf for pointing out and also helping to
    resolve this issue.
    [main.c]
2017-04-11 Firmware: Added additional firmware bootloader check on powerup/reset
    [bootloaderconfig.h, main.c]
2017-04-18 Firmware: All interrupts non-blocking, always service USB interrupts
    Due to failures of USB device enumerations on certain flavors of
    Windows (most notably 8.1), the interrupt service routines have been
    changed to non-blocking behavior and the USB interrupt is no longer
    disabled during rendering. This will assure that USB request are
    always serviced without slight delays caused by the display interrupts
    being serviced. Apparently these delays do not cause problems on Linux
    and older versions of Windows. Nevertheless, this behaviour is more
    correct, although it will cause some display disruptions during USB
    access.
    If you are using Windows and you have trouble getting the device
    correctly de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
    [main.c]
2017-04-20 Firmware: Fixed wrong USB vendor name length in usbconfig.h
    [usbconfig.h]
2017-06-04 Version 1.2
    Changes in this version:
    Software/Firmware:
    - USB interrupts are no longer temporarily disabled during display
    (reported by Richard van der Wolf)
    - Fixed a bug in manual bootloader entry
    - Fixed a parser bug misinterpreting lines containing equal signs as
    symbol definitions (reported by Sven Arke)
    - Fixed build/configure errors on MacOSX (reported by Rene Stopper)
    - Added bash completion support
    Hardware:
    - No changes have been made to the hardware in this release
2017-07-22 Firmware: Fixed slightly skewed first text lines on some monitors
    On some monitors, the display of the first text line may have been
    slightly skewed due to the fact that the SPI line was simply left
    enabled and low throughout the next hsync. Whether or not this
    effect is noticiable seems to depend on the actual input impedance
    of the monitor in use. The SPI line is now tristated after every
    rendered scanline, shortly before the next hsync occurs.
    [main.c]
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2017-11-05 Improved update command for updates that break binary compatibility
    The update command now accepts a configuration file as a second optional
    argument. If specified, the exisitng configuration on the device will be
    erased before updating the firmware and recreated and reflashed after the
    update. This prevents the new firmware from crashing when trying to read
    a deprecated binary configuration format still present on the device.
2024-02-11 Fixed build errors with recent gcc versions, whitespace cleanups
    [config.c, config.h]
2024-02-13 Firmware: Fixed broken firmware build after previous commit
    [config.c]

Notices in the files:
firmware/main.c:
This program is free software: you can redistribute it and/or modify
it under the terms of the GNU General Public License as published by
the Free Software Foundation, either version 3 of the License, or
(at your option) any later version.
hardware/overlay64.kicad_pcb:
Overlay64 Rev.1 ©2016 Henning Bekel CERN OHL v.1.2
